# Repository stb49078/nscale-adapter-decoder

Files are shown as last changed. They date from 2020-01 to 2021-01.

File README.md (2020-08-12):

# Lokdecoder - Adapter Platinen und DIY Decoder - Spur N

Hier finden sich div. Adapterplatinen und vollständige DIY Lokdecoder auf Basis des (vermutlich eingestellten)
Projekts [Aegaeon](https://github.com/Railstars/Aegaeon) von [Railstars](http://railstars.com/).

Wie dieses Projekt auch, stehen die hier veröffentlichten Designs damit automatisch unter GPLv3.

Die Dekoder wurden leicht angeändert, und verwenden den Motortreiber
[BD623xx](http://rohmfs.rohm.com/en/products/databook/datasheet/ic/motor/dc/bd623x-e.pdf).

## Arnold

**1020/E94**

[NEM-651 Adapter](./loc-decoder/Arnold/1020/NEM-651_Adapter)
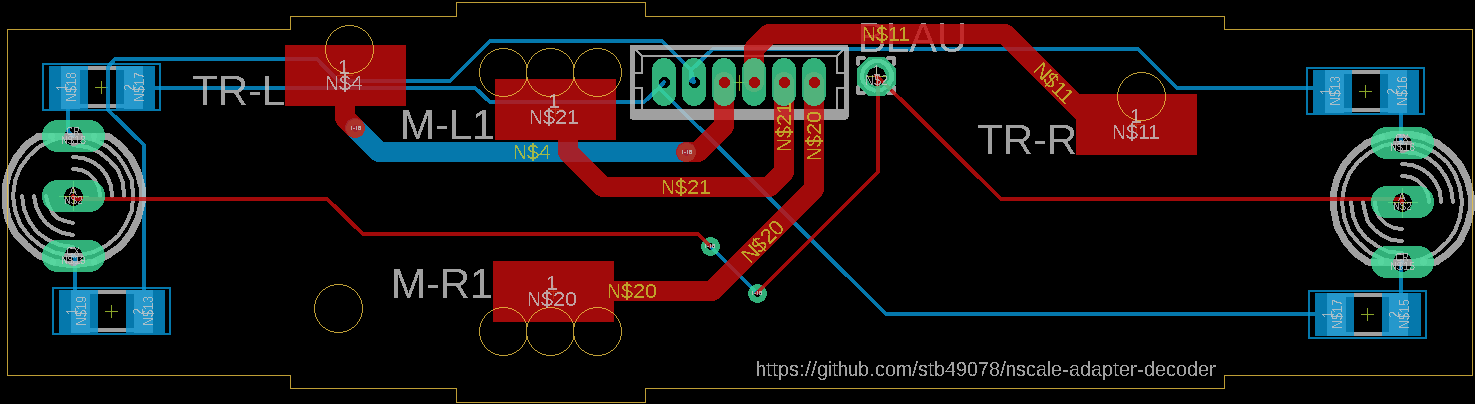
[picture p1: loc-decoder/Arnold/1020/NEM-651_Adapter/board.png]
Board


## Roco

**1044 alt, z.B. 23242**

[NEM-651 Adapter](./loc-decoder/Roco/1044/NEM-651_Adapter)
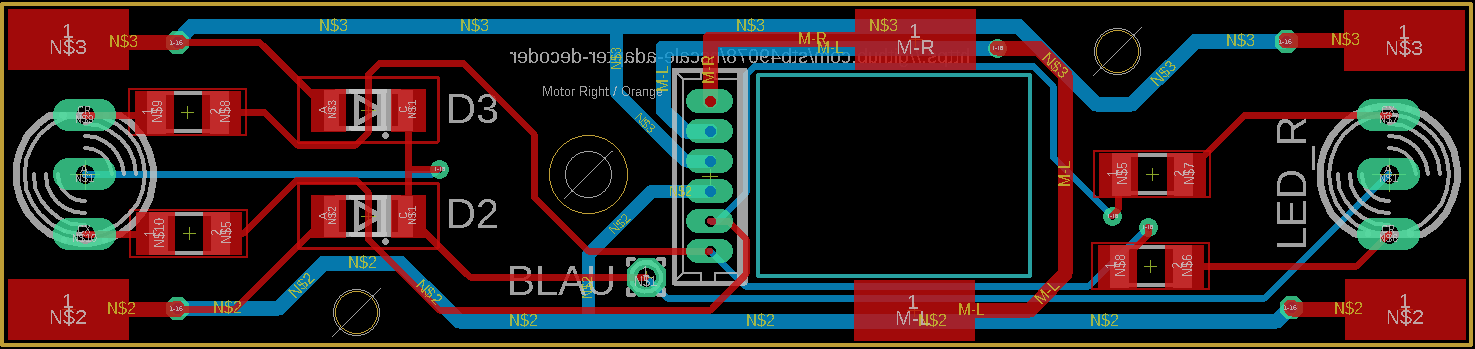
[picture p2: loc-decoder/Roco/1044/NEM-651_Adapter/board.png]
Board


[Aegaeon Decoder mit BD62xx und Railcom](./loc-decoder/Roco/1044/Decoder-BD62xx-Railcom)
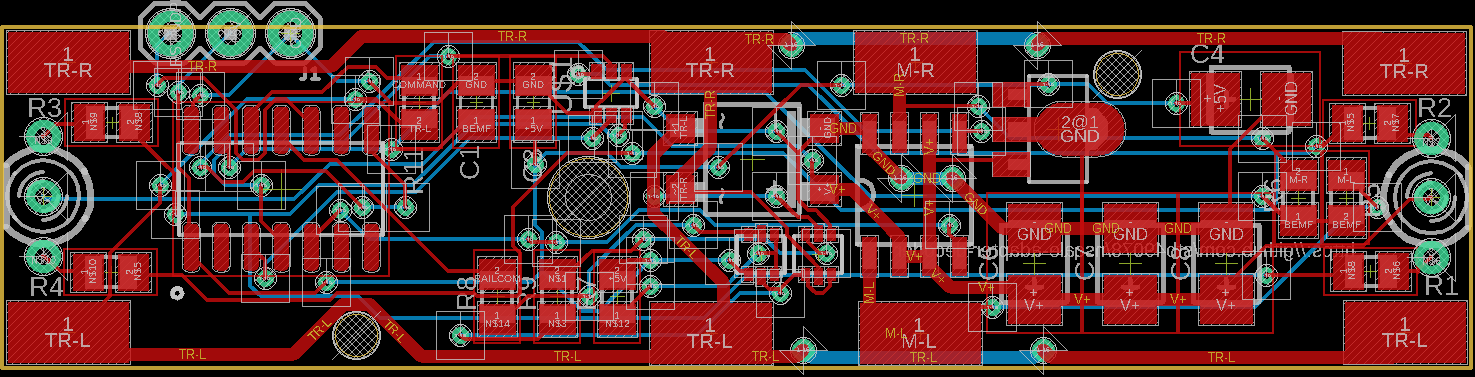
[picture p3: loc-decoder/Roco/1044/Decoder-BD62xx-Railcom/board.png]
Board


**BR215, z.B. 2150B**

[NEM-651 Adapter](./loc-decoder/Roco/BR215/NEM-651_Adapter)
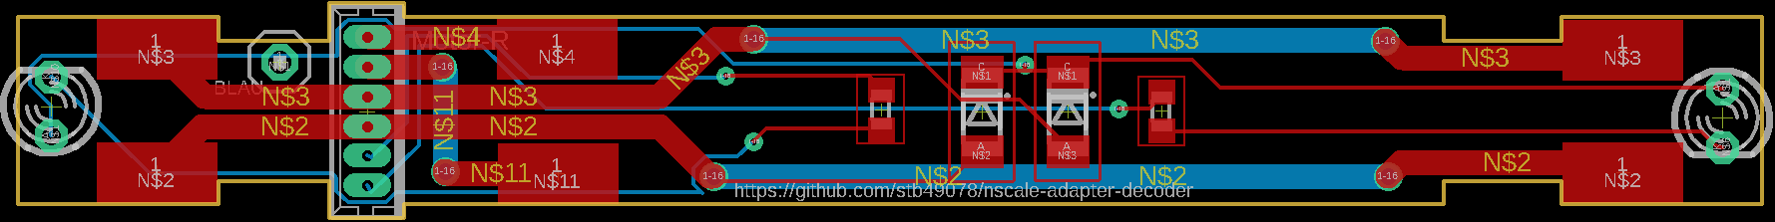
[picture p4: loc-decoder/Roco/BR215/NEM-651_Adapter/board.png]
Board


**BR 44, z.B. 2106B**

[NEM-651 Adapter](./loc-decoder/Roco/BR44/NEM-651_Adapter)
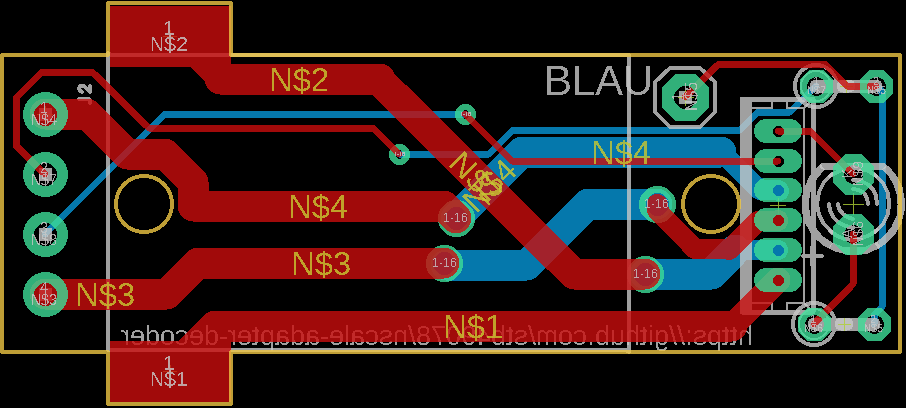
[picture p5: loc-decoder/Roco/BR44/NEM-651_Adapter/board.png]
Board


## Minitrix

**E44**

[NEM-651 Adapter](./loc-decoder/Minitrix/E44/NEM-651_Adapter)
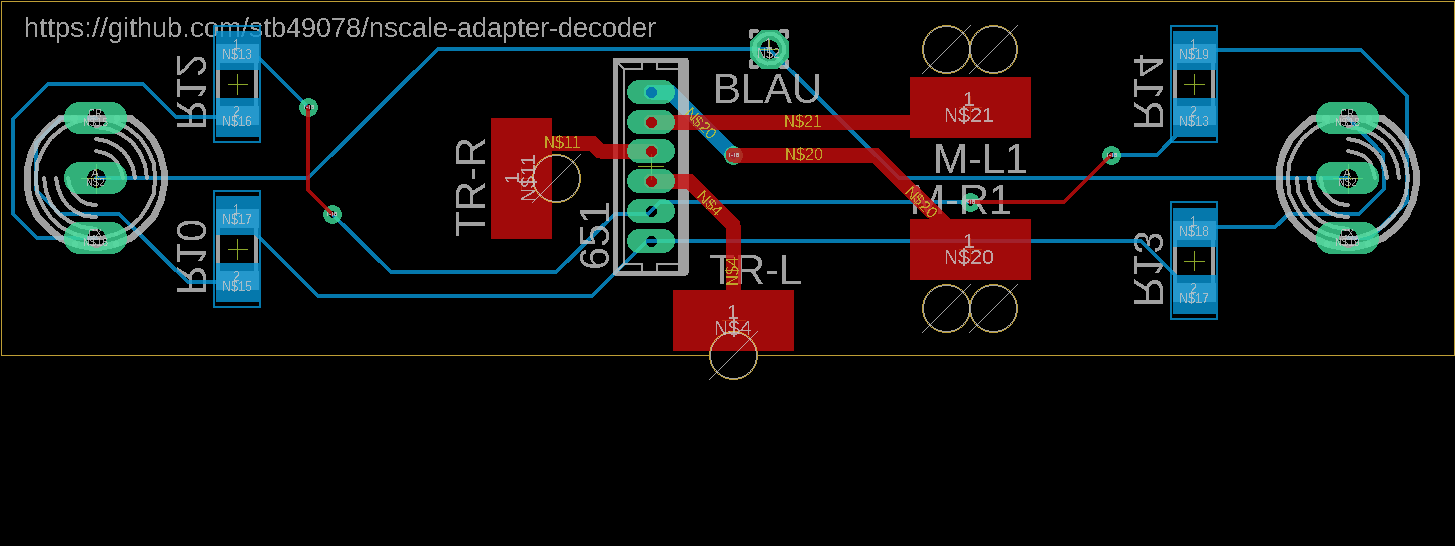
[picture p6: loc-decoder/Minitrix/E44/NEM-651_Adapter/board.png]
Board


## Spectrum

**GE Dash 8-40CW**

[Aegaeon Decoder mit BD62xx und Railcom](./loc-decoder/Spectrum/GE_Dash_8-40CW/Decoder-BD62xx-Railcom)
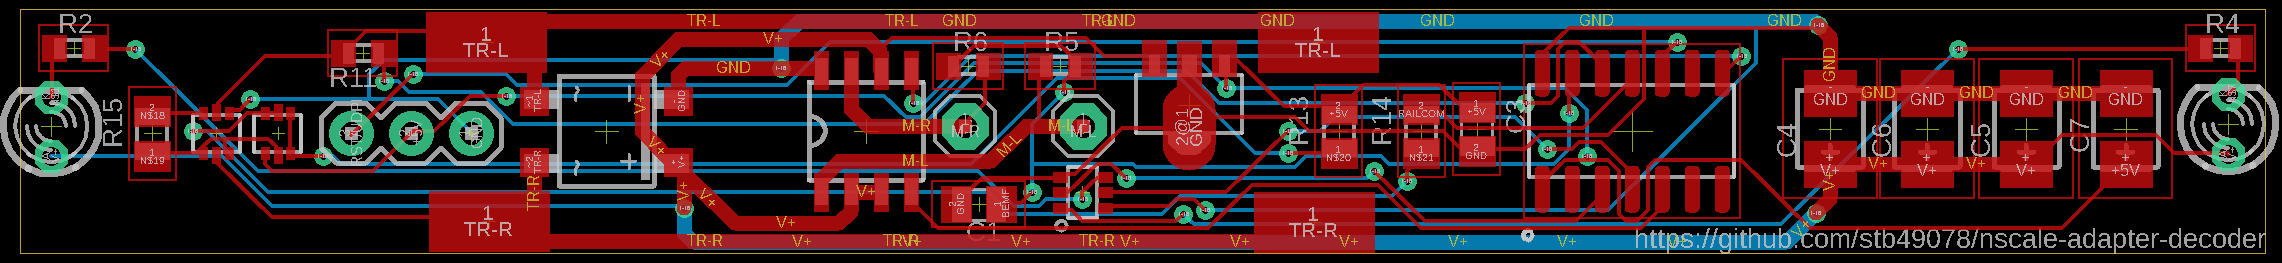
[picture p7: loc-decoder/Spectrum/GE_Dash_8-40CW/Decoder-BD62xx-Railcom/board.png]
Board


# Wagonbeleuchtung mit integriertem Decoder- Spur N

Mit freundlicher Erlaubnis von Hr. Brandt, verwende ich als Basis
für die Wagonbeleuchtung, seinen unter https://www.digital-bahn.de/bau_wald/wald_2v1.htm
veröffentlicheten Spur H0 - Waggon-Licht Dekoder (WaLD) V2.1
Sämtliche Lizenzen für diese Platinen und der darauf verwendeten Software liegen bei digital-bahn.

Diese Platinen werden von meiner Seite nicht zum Verkauf angeboten.
Der Verkauf und/oder Vertrieb eines hier veröffentlichten Designs darf nur unter
Rücksprache mit digital-bahn erfolgen. Copyleft.

Die Anleitung zur Installation der Software und die Schaltungsbeschreibung sind
in der oben genannten Seite zu finden.

Die originale H0-Platine und vorprogrammierte PIC-Controller können im Shop von
digital-bahn unter https://digital-bahn.de/shopping/Waggon-Beleuchtung bezogen werden.  

Folgende Modelle werden aktuell unterstützt:

[Roco - Eurofima z.B. 24270, 24285, uvm.](./wagon-light/Roco/Eurofima)
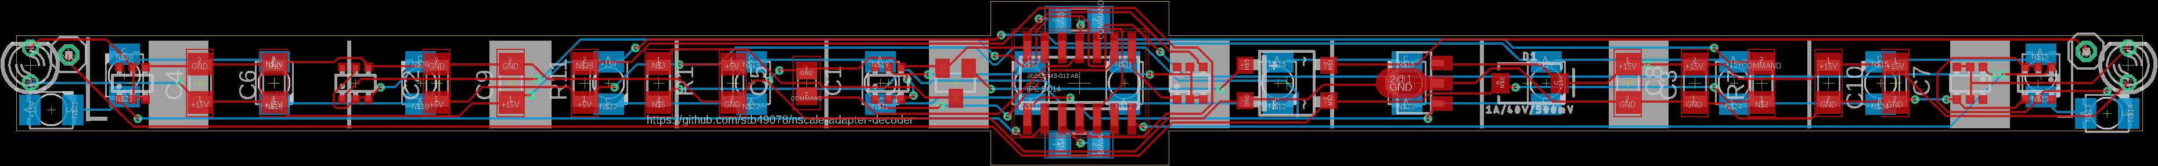
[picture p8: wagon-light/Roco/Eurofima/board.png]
Board


[Roco - Eilzugwagen / Schlierenwagen z.B. 24280-24281 ](./wagon-light/Roco/Eilzugwagen)
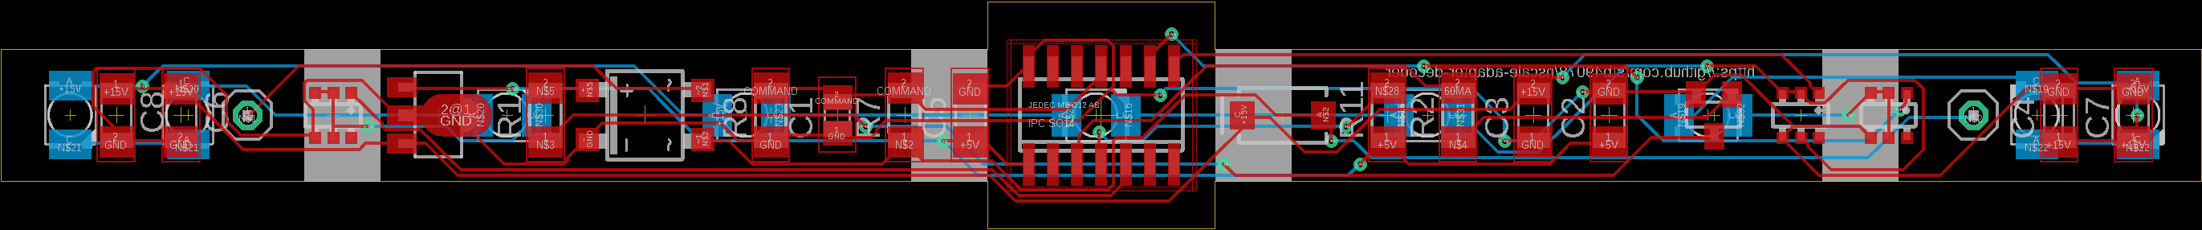
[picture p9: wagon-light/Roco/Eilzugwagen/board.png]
Board


[Minitrix - Eurofima z.B. 3095, 3106, uvm.](./wagon-light/Minitrix/Eurofima)
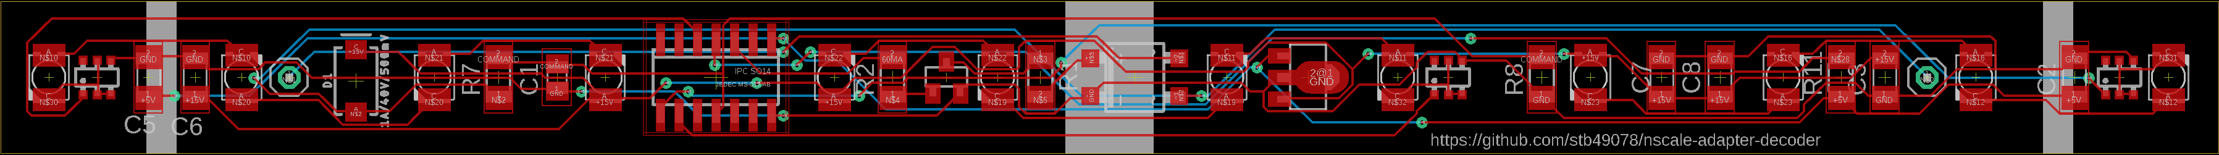
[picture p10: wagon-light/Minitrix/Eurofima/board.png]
Board


Für kleinere Wägen gibt es allgemeine Platinen

[Einseite Montage - 50mm * 15mm](./wagon-light/common/50x15)
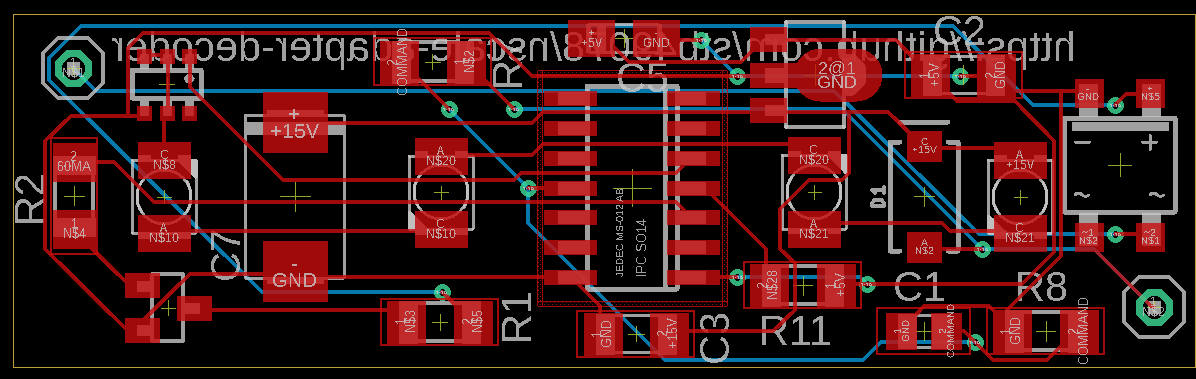
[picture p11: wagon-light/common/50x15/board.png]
Board


## Support und Fragen

Bei Fragen, Anregungen und Beschwerden, bitte einfach unter spur.n@stefanbauer.at melden.

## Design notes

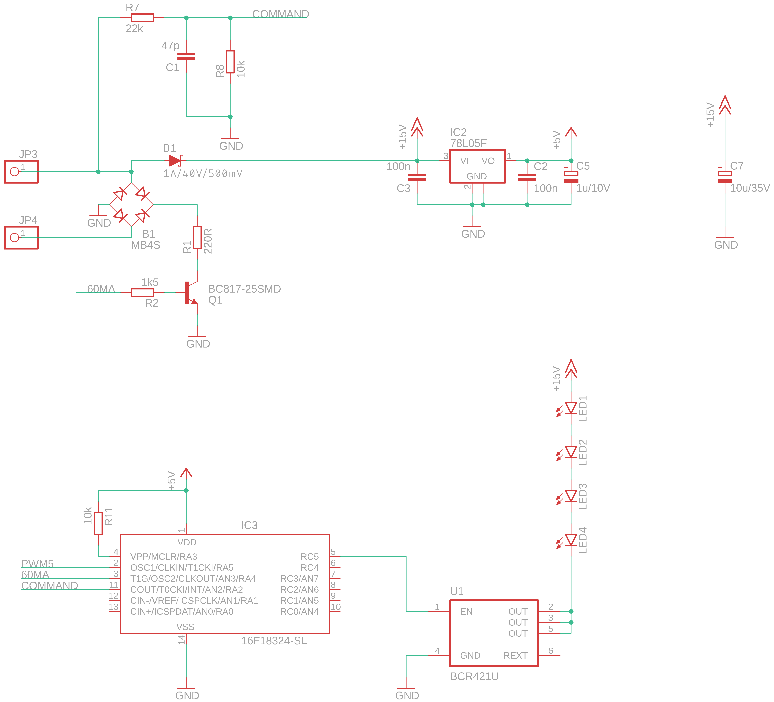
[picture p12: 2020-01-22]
wagon-light/common/50x15/schematic.png

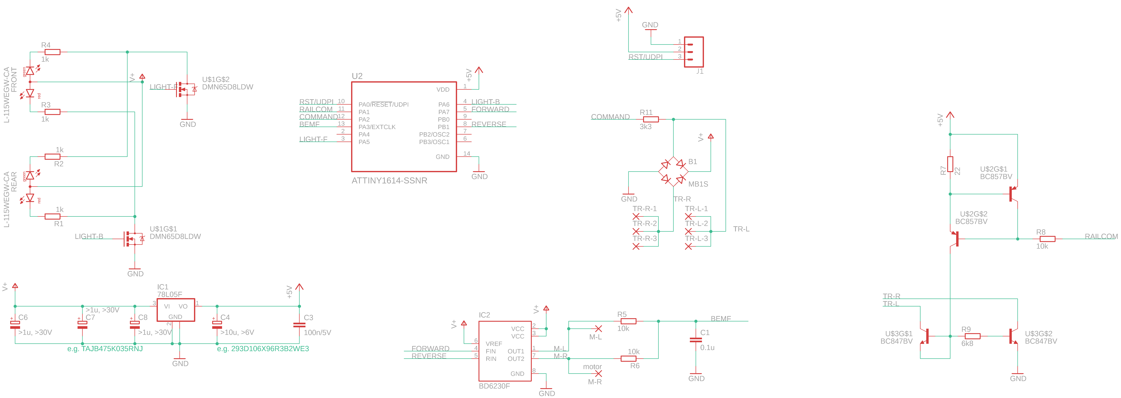
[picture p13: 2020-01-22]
loc-decoder/Roco/1044/Decoder-BD62xx-Railcom/schematic.png

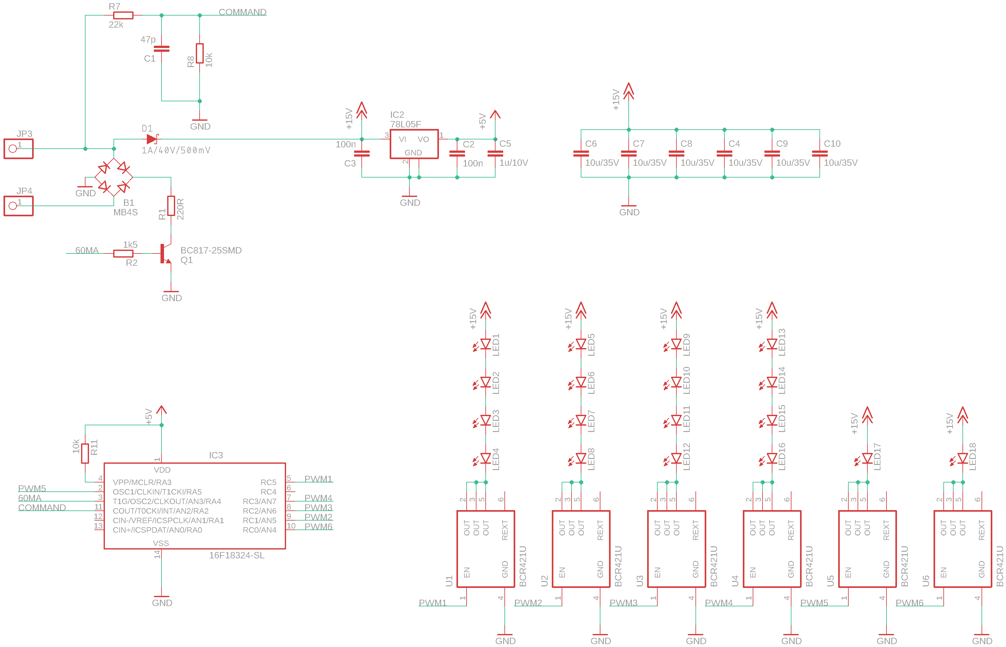
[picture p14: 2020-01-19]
wagon-light/Roco/Eurofima/schematic.png

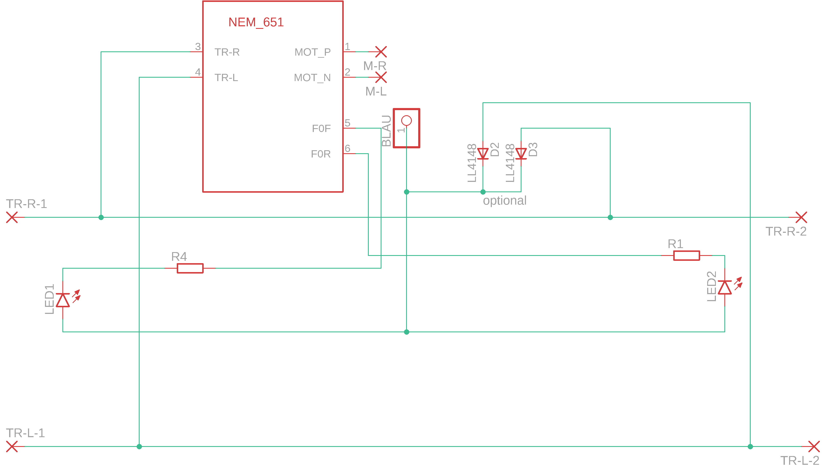
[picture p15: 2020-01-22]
loc-decoder/Roco/BR215/NEM-651_Adapter/schematic.png

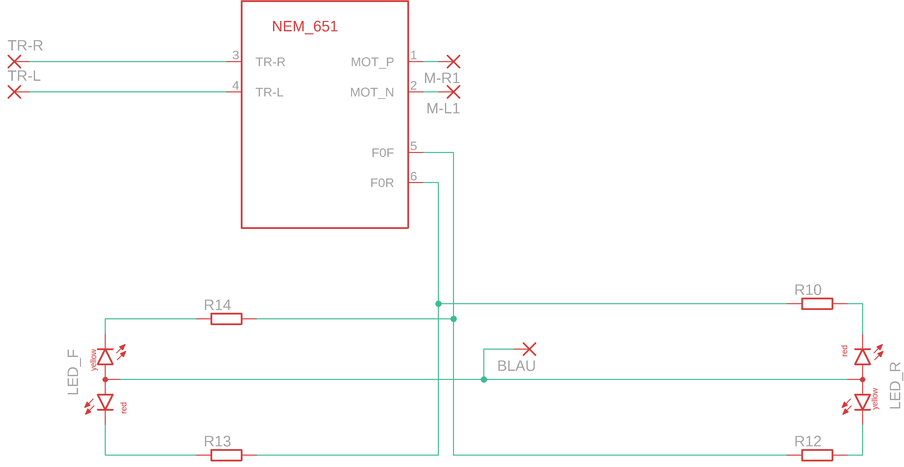
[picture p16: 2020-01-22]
loc-decoder/Minitrix/E44/NEM-651_Adapter/schematic.png

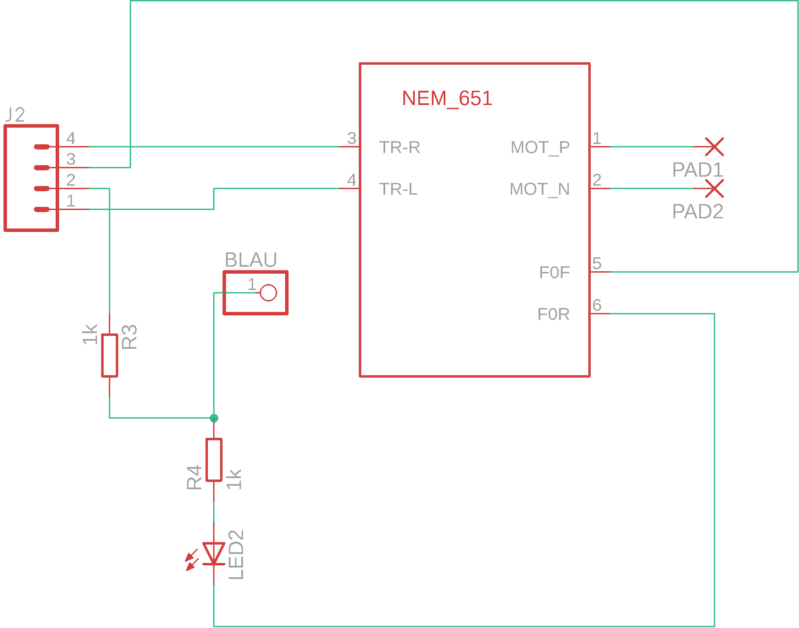
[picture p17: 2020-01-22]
loc-decoder/Roco/BR44/NEM-651_Adapter/schematic.png

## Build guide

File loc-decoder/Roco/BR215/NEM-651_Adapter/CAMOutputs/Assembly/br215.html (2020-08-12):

Stückliste exportiert aus D:/nscale-adapter-decoder/loc-decoder/Roco/BR215/br215.sch am 22.01.2020 22:11

Qty | Value | Device | Package | Parts | Description | POPULARITY | SPICEPREFIX
2 | | LED3MM | LED3MM | LED1, LED2 | LED
1 | | PINHD-1X1 | 1X01 | BLAU | PIN HEADER | 64
2 | | R-EU_R0603 | R0603 | R1, R4 | RESISTOR, European symbol | | R
6 | | SMD5 | SMD2,54-5,08 | M-L, M-R, TR-L-1, TR-L-2, TR-R-1, TR-R-2 | SMD PAD
2 | LL4148 | LL4148 | SOD80_DO213AA_MINIMELF | D2, D3 | 1N4148 General Purpose Rectifie
1 | NEM_651-TS | NEM_651-TS | 53047-06 | 651 | NEM651

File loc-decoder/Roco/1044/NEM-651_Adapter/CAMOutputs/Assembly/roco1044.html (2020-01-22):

Stückliste exportiert aus D:/nscale-adapter-decoder/loc-decoder/Roco/1044/NEM-651 Adapter/roco1044.sch am 22.01.2020 21:57

Qty | Value | Device | Package | Parts | Description | SPICEPREFIX
1 | | 1,6/0,8 | 1,6/0,8 | BLAU | THROUGH-HOLE PAD
2 | | DUOLED-RY-A | DUOLED-A-5MM | LED_F, LED_R | DUO LED
4 | | R-EU_R1206 | R1206 | R1, R2, R3, R4 | RESISTOR, European symbol | R
6 | | SMD5 | SMD2,54-5,08 | M-L, M-R, TR-L-1, TR-L-2, TR-R-1, TR-R-2 | SMD PAD
2 | LL4148 | LL4148 | SOD80_DO213AA_MINIMELF | D2, D3 | 1N4148 General Purpose Rectifie
1 | NEM_651-TS | NEM_651-TS | 53047-06 | 651 | NEM651

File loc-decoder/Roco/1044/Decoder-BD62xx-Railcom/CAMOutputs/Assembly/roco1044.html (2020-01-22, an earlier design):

Stückliste exportiert aus D:/nscale-adapter-decoder/loc-decoder/Roco/1044/Decoder-BD62xx-Railcom/roco1044.sch am 22.01.2020 22:04

Qty | Value | Device | Package | Parts | Description | AVAILABILITY | DESCRIPTION | MF | MP | MPN | OC_FARNELL | OC_NEWARK | PACKAGE | POPULARITY | PRICE | PROD_ID | SPICEPREFIX | VALUE
7 | | SMD5 | SMD2,54-5,08 | M-L, TR-L-1, TR-L-2, TR-L-3, TR-R-1, TR-R-2, TR-R-3 | SMD PAD
1 | 0.1u | C-EUC0805 | C0805 | C1 | CAPACITOR, European symbol
1 | 100n/5V | C-EUC0805 | C0805 | C3 | CAPACITOR, European symbol | | | | | | | | | | | | C
3 | 10k | R-EU_R0805 | R0805 | R5, R6, R8 | RESISTOR, European symbol | | | | | | | | | 86 | | | R
4 | 1k | R-EU_R0805 | R0805 | R1, R2, R3, R4 | RESISTOR, European symbol | | | | | | | | | 86 | | | R
1 | 22 | R-EU_R0805 | R0805 | R7 | RESISTOR, European symbol | | | | | | | | | 86 | | | R
1 | 3k3 | R-EU_R0805 | R0805 | R11 | RESISTOR, European symbol | | | | | | | | | 86 | | | R
1 | 455-1750-1-ND | CONN_03 | 1X03 | J1 | Multi connection point. Often used as Generic Header-pin footprint for 0.1 inch spaced/style header connections | | | | | | | | | | | XXX-00000 | | 455-1750-1-ND
1 | 6k8 | R-EU_R0805 | R0805 | R9 | RESISTOR, European symbol | | | | | | | | | 86 | | | R
1 | 78L05F | 78L05F | SOT89 | IC1 | POSITOIV-VOLTAGE REGULATORS
1 | >10u, >6V | CPOL-EUCT3528 | CT3528 | C4 | POLARIZED CAPACITOR, European symbol | | | | | | | | | 1 | | | C
3 | >1u, >30V | CPOL-EUCT3528 | CT3528 | C6, C7, C8 | POLARIZED CAPACITOR, European symbol | | | | | | | | | 1 | | | C
1 | ATTINY1614-SSNR | ATTINY1614-SSNR | SOIC127P600X175-14N | U2 | 20MHz, SOIC, 85C, Green, 14 SOIC .150in T/R | Unavailable | AVR tinyAVR™ 1 Microcontroller IC 8-Bit 20MHz 16KB _16K x 8_ FLASH 14-SOIC | Microchip | ATTINY1614-SSNR | | | | SO-14 Microchip | | None
1 | BC847BV | BC847BV | SOT-666 | U$3
1 | BC857BV | BC857BV | SOT-666 | U$2
1 | BD6230F | BD6230F | SOP8 | IC2 | H-bridge driver for brush motors | | | | | BD6230F-E2 | 1716264 | 15R0529
1 | DMN65D8LDW | DMN65D8LDW | SOT363 | U$1
2 | L-115WEGW-CA | L-115WEGW-CA | DUOLED-A-3MM | FRONT, REAR | T-1(3mm) BI-COLOR INDICATOR LAMP
1 | MB1S | MB1S | SOIC-4 | B1 | Bridge Rectifier
1 | motor | SMD5 | SMD2,54-5,08 | M-R | SMD PAD

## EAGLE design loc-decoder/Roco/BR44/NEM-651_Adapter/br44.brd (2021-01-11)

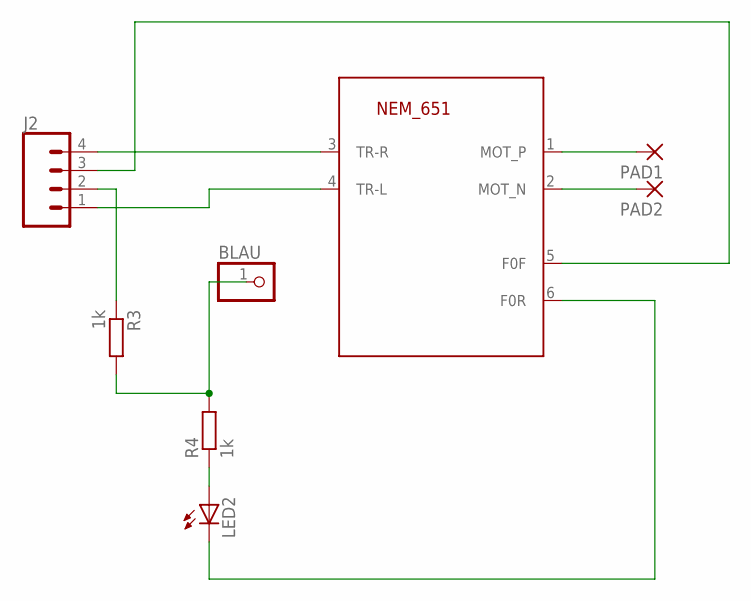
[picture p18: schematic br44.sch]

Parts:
BLAU: PINHD-1X1; 1X01
J2: CONN_041X04_NO_SILK; 1X04_NO_SILK
LED2: LED3MM
PAD1, PAD2: SMD5; SMD2,54-5,08
R3, R4: 1k; 0204V
U$1: NEM_651-TS; 53047-06

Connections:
unnamed: PAD1.1, U$1.1 (MOT_P)
unnamed: PAD2.1, U$1.2 (MOT_N)
unnamed: J2.4, U$1.3 (TR-R)
unnamed: J2.1, U$1.4 (TR-L)
unnamed: BLAU.1, R3.2, R4.2
unnamed: LED2.A, R4.1
unnamed: J2.2, R3.1
unnamed: J2.3, U$1.5 (F0F)
unnamed: LED2.K (C), U$1.6 (F0R)

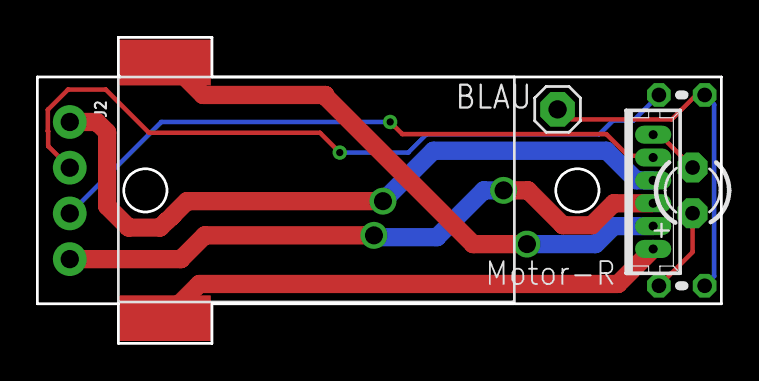
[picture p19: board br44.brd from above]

Board: 2 copper layers, 38.0 x 17.0 mm, 8 parts (0 on the bottom side), 9 nets.

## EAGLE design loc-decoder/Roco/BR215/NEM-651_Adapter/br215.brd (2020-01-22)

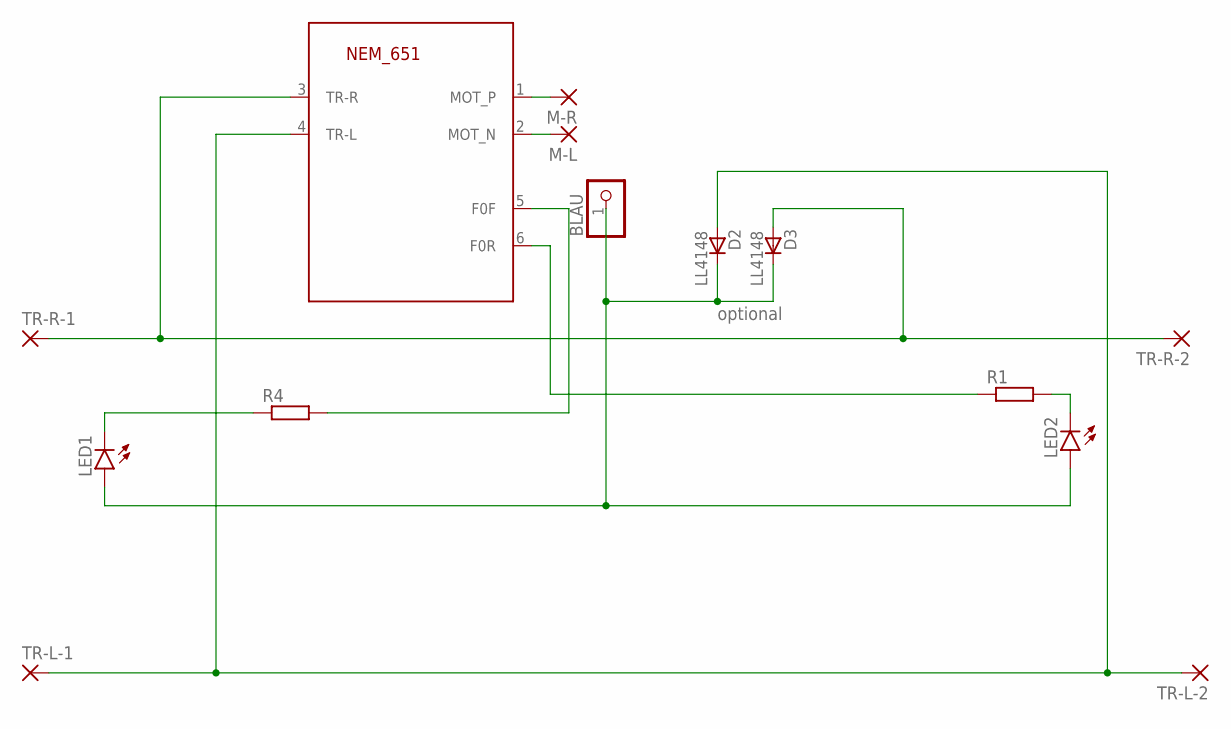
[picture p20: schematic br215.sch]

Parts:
651: NEM_651-TS; 53047-06
BLAU: PINHD-1X1; 1X01
D2, D3: LL4148; SOD80_DO213AA_MINIMELF
LED1, LED2: LED3MM
M-L: SMD5; SMD2,54-5,08
M-R: SMD5; SMD2,54-5,08
R1, R4: R-EU_R0603; R0603
TR-L-1, TR-L-2: SMD5; SMD2,54-5,08
TR-R-1, TR-R-2: SMD5; SMD2,54-5,08

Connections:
unnamed: BLAU.1, D2.C, D3.C, LED1.A, LED2.A
unnamed: 651.4 (TR-L), D2.A, TR-L-1.1, TR-L-2.1
unnamed: 651.3 (TR-R), D3.A, TR-R-1.1, TR-R-2.1
unnamed: 651.1 (MOT_P), M-R.1
unnamed: 651.5 (F0F), R4.2
unnamed: LED2.K (C), R1.2
unnamed: 651.6 (F0R), R1.1
unnamed: LED1.K (C), R4.1
unnamed: 651.2 (MOT_N), M-L.1

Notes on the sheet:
optional

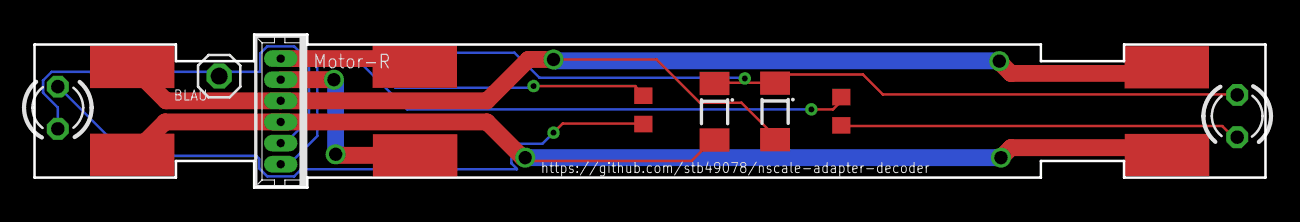
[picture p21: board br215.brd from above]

Board: 2 copper layers, 74.0 x 9.2 mm, 14 parts (0 on the bottom side), 9 nets.

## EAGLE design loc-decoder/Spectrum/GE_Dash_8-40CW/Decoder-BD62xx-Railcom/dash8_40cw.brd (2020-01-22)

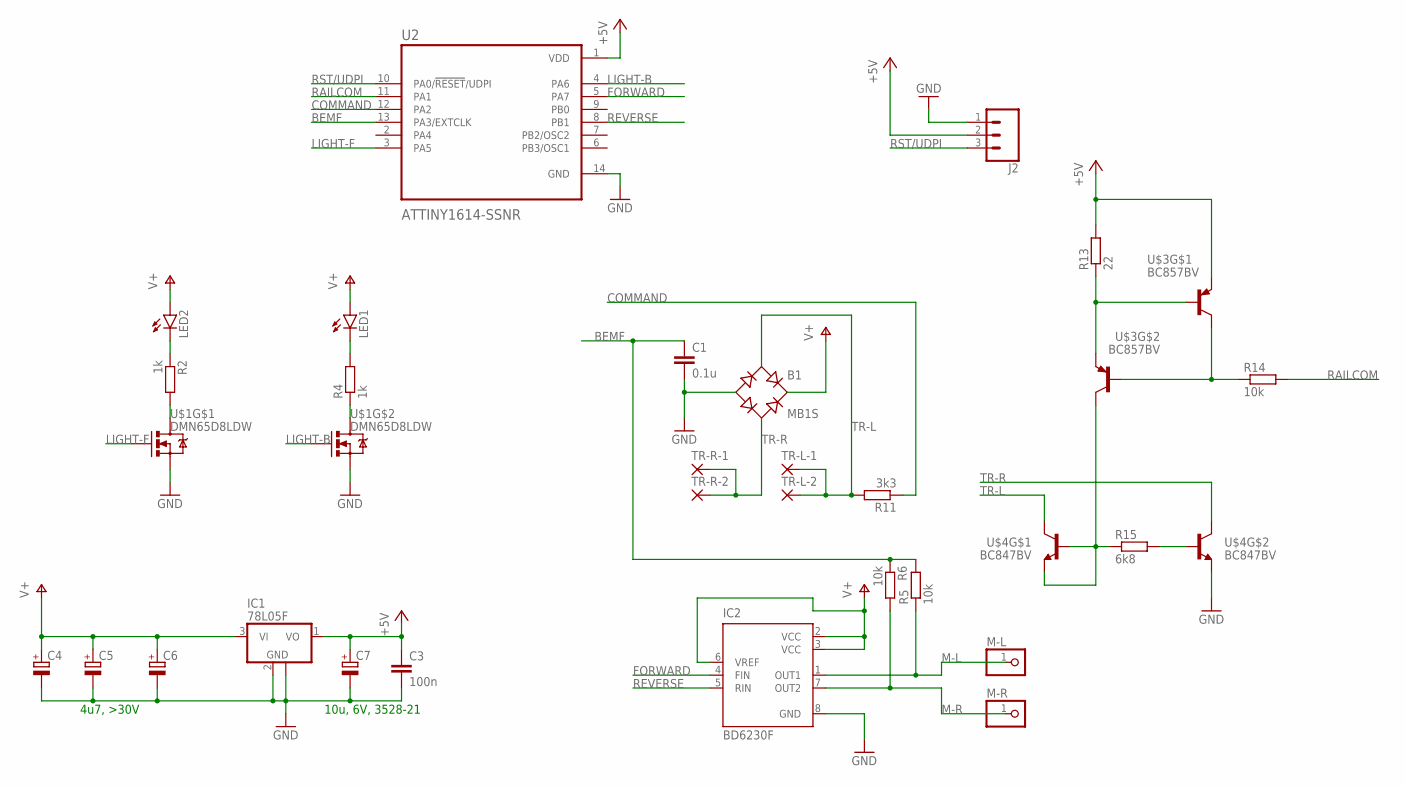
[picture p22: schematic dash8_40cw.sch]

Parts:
B1: MB1S; SOIC-4
C1: 0.1u; C0805
C3: 100n; C0805
C4, C5, C6, C7: CPOL-EUCT3528; CT3528
IC1: 78L05F; SOT89
IC2: BD6230F; SOP8
J2: 455-1750-1-ND; 1X03
LED1, LED2: LED3MM
M-L: PINHD-1X1; 1X01
M-R: PINHD-1X1; 1X01
R2, R4: 1k; R0603
R5, R6: 10k; R0603
R11: 3k3; R0603
R13: 22; R0805
R14: 10k; R0805
R15: 6k8; R0805
TR-L-1, TR-L-2: SMD5; SMD2,54-5,08
TR-R-1, TR-R-2: SMD5; SMD2,54-5,08
U2: ATTINY1614-SSNR; SOIC127P600X175-14N
U$1: DMN65D8LDW; SOT363
U$3: BC857BV; SOT-666
U$4: BC847BV; SOT-666

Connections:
+5V: C3.1, C7.+, IC1.1 (VO), J2.2, R13.2, U2.1 (VDD), U$3.P$1 (E)
BEMF: C1.1, R5.2, R6.1, U2.13 (PA3/EXTCLK)
COMMAND: R11.1, U2.12 (PA2)
FORWARD: IC2.4 (FIN), U2.5 (PA7)
GND: B1.-, C1.2, C3.2, C4.-, C5.-, C6.-, C7.-, IC1.2 (GND), IC1.2@1 (GND), IC2.8 (GND), J2.1, U2.14 (GND), U$1.P$3 (S), U$1.P$6 (S), U$4.P$4 (E)
LIGHT-B: U2.4 (PA6), U$1.P$5 (G)
LIGHT-F: U2.3 (PA5), U$1.P$2 (G)
M-L: IC2.1 (OUT1), M-L.1, R5.1
M-R: IC2.7 (OUT2), M-R.1, R6.2
unnamed: LED2.K (C), R2.1
unnamed: R4.1, U$1.P$1 (D)
unnamed: R2.2, U$1.P$4 (D)
unnamed: LED1.K (C), R4.2
unnamed: R15.2, U$4.P$5 (B)
unnamed: R15.1, U$3.P$3 (C), U$4.P$1 (E), U$4.P$2 (B)
unnamed: R13.1, U$3.P$2 (B), U$3.P$4 (E)
unnamed: R14.1, U$3.P$5 (B), U$3.P$6 (C)
RAILCOM: R14.2, U2.11 (PA1)
REVERSE: IC2.5 (RIN), U2.8 (PB1)
RST/UDPI: J2.3, U2.10 (PA0/!RESET!/UDPI)
TR-L: B1.~1 (AC1), R11.2, TR-L-1.1, TR-L-2.1, U$4.P$6 (C)
TR-R: B1.~2 (AC2), TR-R-1.1, TR-R-2.1, U$4.P$3 (C)
V+: B1.+, C4.+, C5.+, C6.+, IC1.3 (VI), IC2.2 (VCC), IC2.3 (VCC), IC2.6 (VREF), LED1.A, LED2.A

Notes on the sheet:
4u7, >30V
10u, 6V, 3528-21

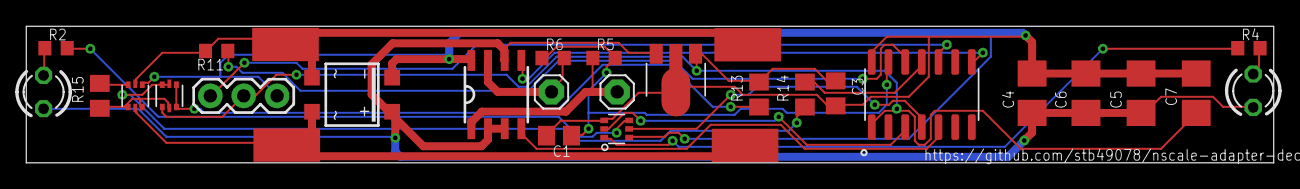
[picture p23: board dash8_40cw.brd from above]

Board: 2 copper layers, 95.0 x 10.4 mm, 30 parts (0 on the bottom side), 23 nets.

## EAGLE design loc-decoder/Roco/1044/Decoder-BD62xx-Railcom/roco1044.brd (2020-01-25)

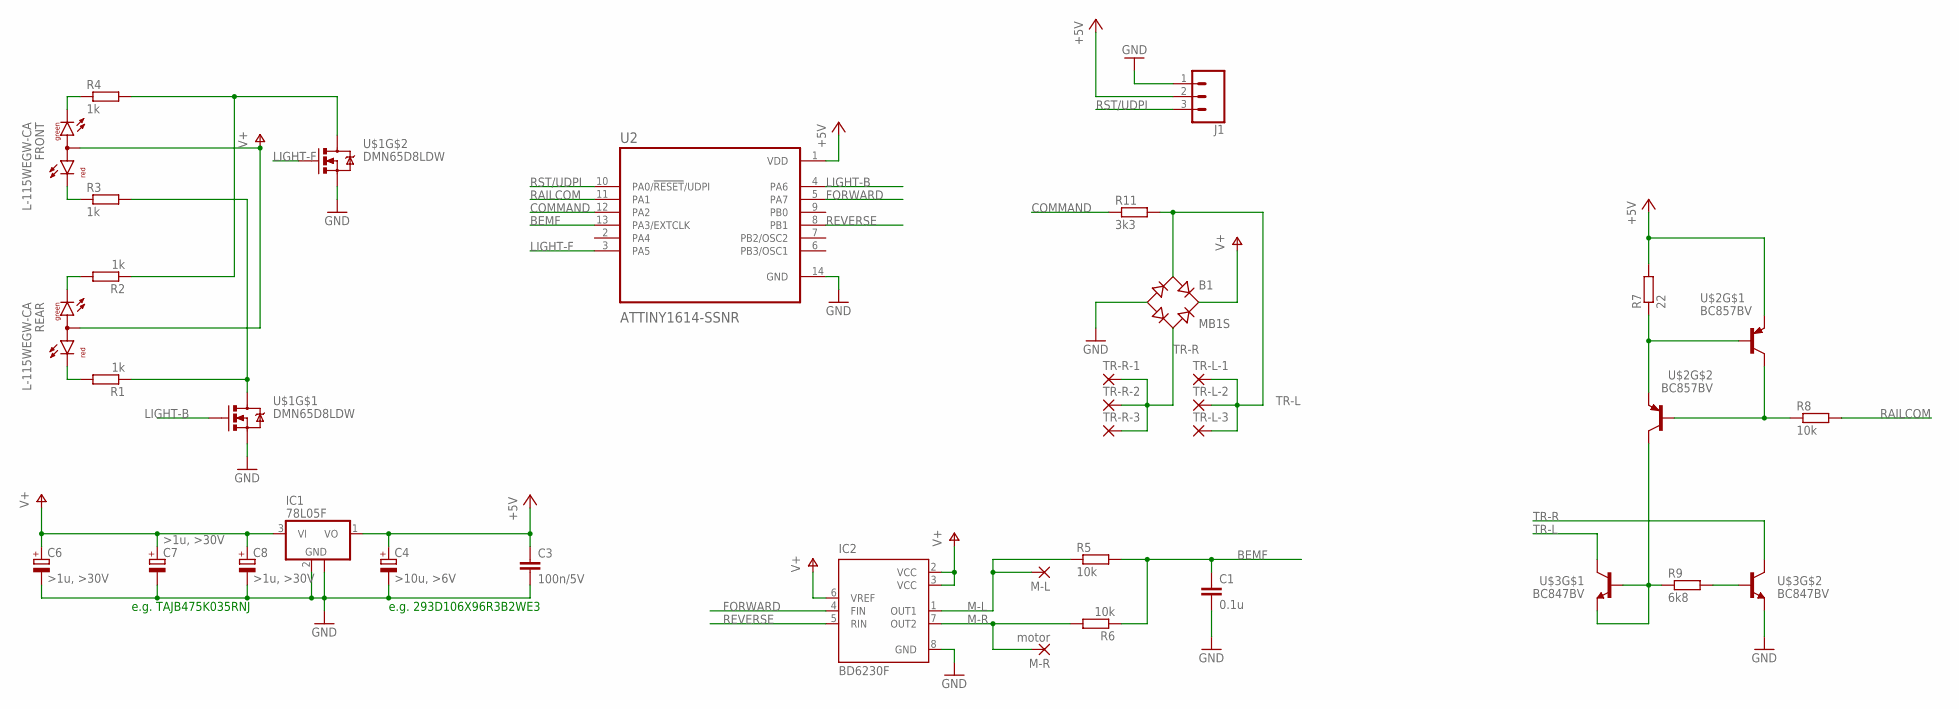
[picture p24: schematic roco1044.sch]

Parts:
B1: MB1S; SOIC-4
C1: 0.1u; C0805
C3: 100n/5V; C0805
C4: >10u, >6V; CT3528
C6, C7, C8: >1u, >30V; CT3528
FRONT: L-115WEGW-CA; DUOLED-A-3MM
IC1: 78L05F; SOT89
IC2: BD6230F; SOP8
J1: 455-1750-1-ND; 1X03
M-L: SMD5; SMD2,54-5,08
M-R: motor; SMD2,54-5,08
R1, R2, R3, R4: 1k; R0805
R5, R6, R8: 10k; R0805
R7: 22; R0805
R9: 6k8; R0805
R11: 3k3; R0805
REAR: L-115WEGW-CA; DUOLED-A-3MM
TR-L-1, TR-L-2, TR-L-3: SMD5; SMD2,54-5,08
TR-R-1, TR-R-2, TR-R-3: SMD5; SMD2,54-5,08
U2: ATTINY1614-SSNR; SOIC127P600X175-14N
U$1: DMN65D8LDW; SOT363
U$2: BC857BV; SOT-666
U$3: BC847BV; SOT-666

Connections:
+5V: C3.1, C4.+, IC1.1 (VO), J1.2, R7.2, U2.1 (VDD), U$2.P$1 (E)
BEMF: C1.1, R5.2, R6.1, U2.13 (PA3/EXTCLK)
COMMAND: R11.1, U2.12 (PA2)
FORWARD: IC2.4 (FIN), U2.5 (PA7)
GND: B1.-, C1.2, C3.2, C4.-, C6.-, C7.-, C8.-, IC1.2 (GND), IC1.2@1 (GND), IC2.8 (GND), J1.1, U2.14 (GND), U$1.P$3 (S), U$1.P$6 (S), U$3.P$4 (E)
LIGHT-B: U2.4 (PA6), U$1.P$2 (G)
LIGHT-F: U2.3 (PA5), U$1.P$5 (G)
M-L: IC2.1 (OUT1), M-L.1, R5.1
M-R: IC2.7 (OUT2), M-R.1, R6.2
unnamed: R9.2, U$3.P$5 (B)
unnamed: R9.1, U$2.P$3 (C), U$3.P$1 (E), U$3.P$2 (B)
unnamed: R2.1, R4.2, U$1.P$1 (D)
unnamed: R1.2, REAR.3 (CR)
unnamed: R2.2, REAR.1 (CG)
unnamed: R1.1, R3.2, U$1.P$4 (D)
unnamed: FRONT.3 (CR), R3.1
unnamed: FRONT.1 (CG), R4.1
unnamed: R7.1, U$2.P$2 (B), U$2.P$4 (E)
unnamed: R8.1, U$2.P$5 (B), U$2.P$6 (C)
RAILCOM: R8.2, U2.11 (PA1)
REVERSE: IC2.5 (RIN), U2.8 (PB1)
RST/UDPI: J1.3, U2.10 (PA0/!RESET!/UDPI)
TR-L: B1.~1 (AC1), R11.2, TR-L-1.1, TR-L-2.1, TR-L-3.1, U$3.P$6 (C)
TR-R: B1.~2 (AC2), TR-R-1.1, TR-R-2.1, TR-R-3.1, U$3.P$3 (C)
V+: B1.+, C6.+, C7.+, C8.+, FRONT.2 (A), IC1.3 (VI), IC2.2 (VCC), IC2.3 (VCC), IC2.6 (VREF), REAR.2 (A)

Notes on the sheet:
e.g. TAJB475K035RNJ
e.g. 293D106X96R3B2WE3

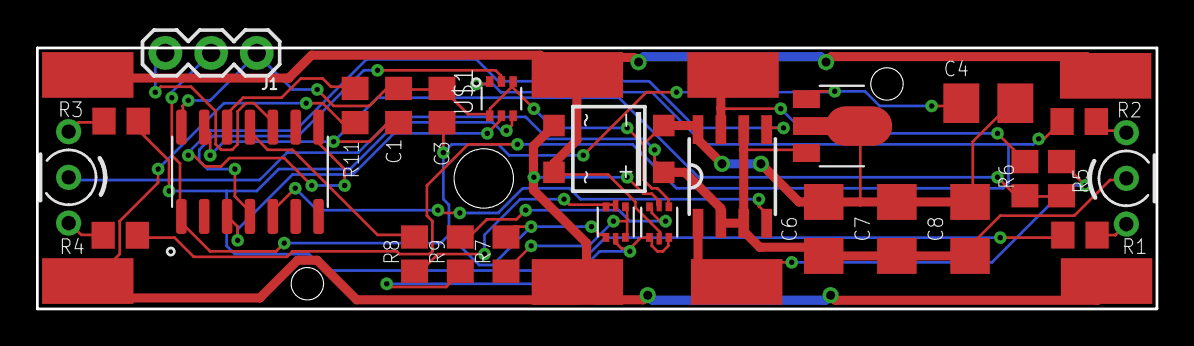
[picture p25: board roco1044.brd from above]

Board: 2 copper layers, 62.2 x 14.5 mm, 34 parts (0 on the bottom side), 25 nets.

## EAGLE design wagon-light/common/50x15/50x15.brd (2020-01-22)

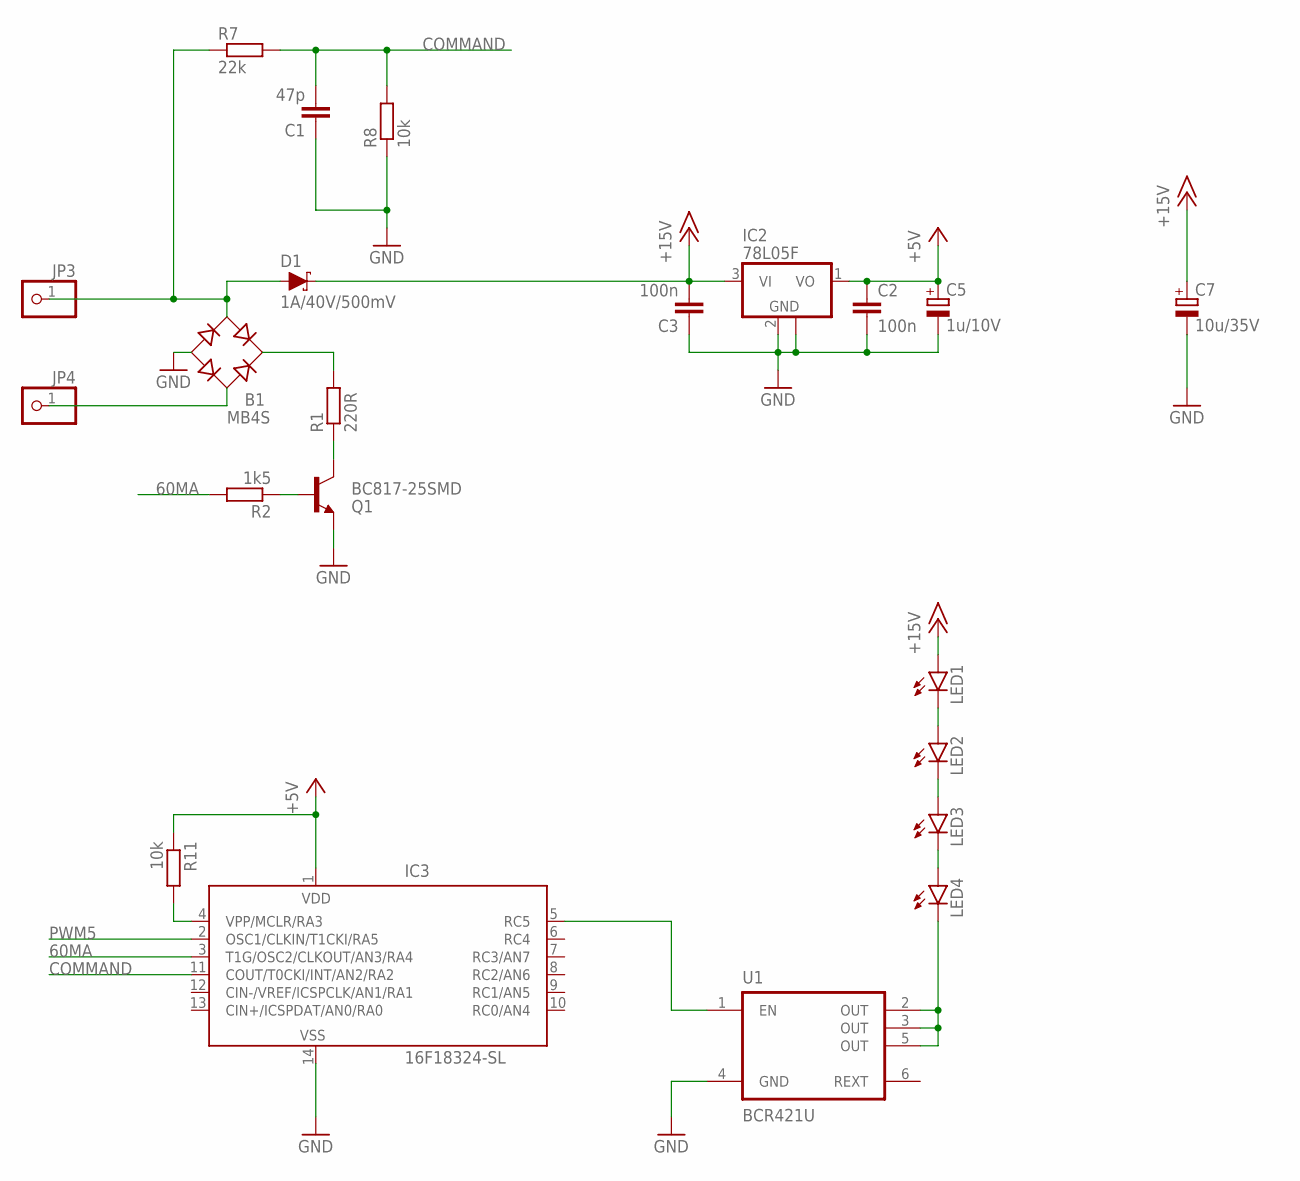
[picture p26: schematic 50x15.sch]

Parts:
B1: MB4S; SOIC-4
C1: 47p; C0805
C2, C3: 100n; C3216
C5: 1u/10V; A/3216-18R
C7: 10u/35V; D/7343-31R
D1: 1A/40V/500mV; SMA-DIODE
IC2: 78L05F; SOT89
IC3: 16F18324-SL; SO-14
JP3, JP4: PINHD-1X1; 1X01
LED1, LED2, LED3, LED4: LEDKA-3528ASYC; KA-3528ASYC
Q1: BC817-25SMD; SOT23-BEC
R1: 220R; R1206
R2: 1k5; R1206
R7: 22k; R1206
R8, R11: 10k; R1206
U1: BCR421U; SC74-6

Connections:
60MA: IC3.3 (T1G/OSC2/CLKOUT/AN3/RA4), R2.2
+5V: C2.1, C5.+, IC2.1 (VO), IC3.1 (VDD), R11.1
+15V: C3.2, C7.+, D1.C, IC2.3 (VI), LED1.A
COMMAND: C1.2, IC3.11 (COUT/T0CKI/INT/AN2/RA2), R7.2, R8.2
GND: B1.-, C1.1, C2.2, C3.1, C5.-, C7.-, IC2.2 (GND), IC2.2@1 (GND), IC3.14 (VSS), Q1.E, R8.1, U1.4 (GND)
unnamed: B1.~2 (AC2), JP4.1
unnamed: B1.~1 (AC1), D1.A, JP3.1, R7.1
unnamed: Q1.C, R1.1
unnamed: Q1.B, R2.1
unnamed: B1.+, R1.2
unnamed: IC3.5 (RC5), U1.1 (EN)
unnamed: LED4.C, U1.2 (OUT), U1.3 (OUT), U1.5 (OUT)
unnamed: LED3.C, LED4.A
unnamed: LED2.C, LED3.A
unnamed: LED1.C, LED2.A
unnamed: IC3.4 (VPP/MCLR/RA3), R11.2
PWM5: IC3.2 (OSC1/CLKIN/T1CKI/RA5)

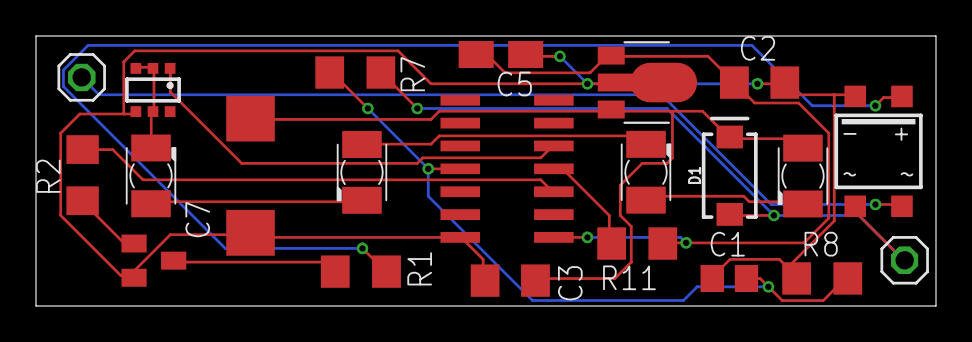
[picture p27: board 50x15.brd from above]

Board: 2 copper layers, 50.0 x 15.0 mm, 22 parts (0 on the bottom side), 16 nets.

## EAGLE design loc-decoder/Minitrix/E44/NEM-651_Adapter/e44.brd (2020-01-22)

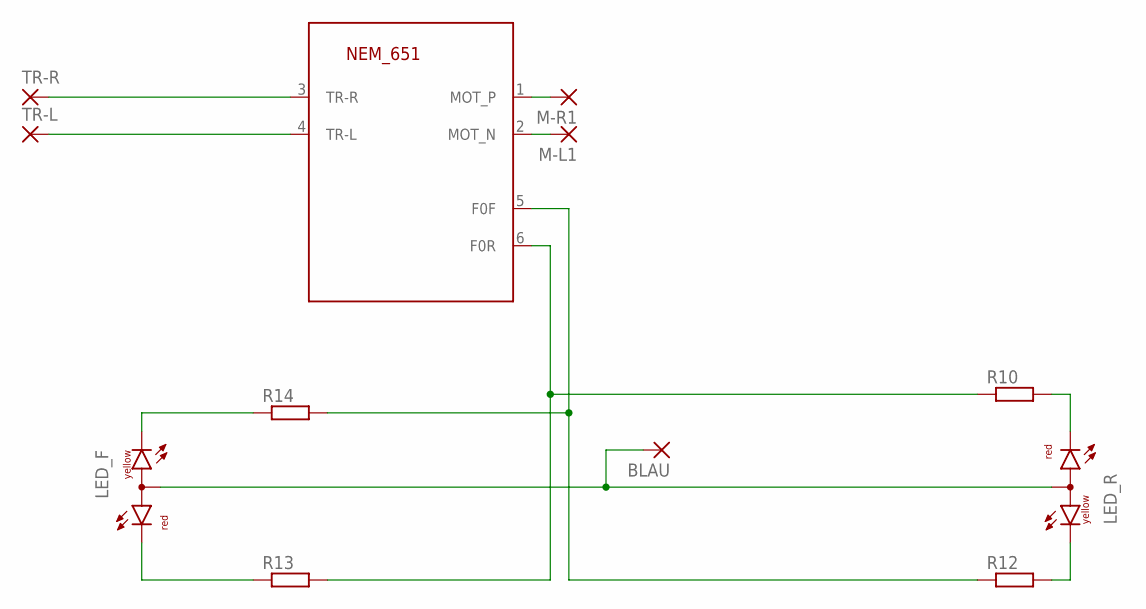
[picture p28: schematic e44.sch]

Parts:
651: NEM_651-TS; 53047-06
BLAU: 1,6/0,8
LED_F: DUOLED-RY-A; DUOLED-A-5MM
LED_R: DUOLED-RY-A; DUOLED-A-5MM
M-L1: SMD5; SMD2,54-5,08
M-R1: SMD5; SMD2,54-5,08
R10, R12, R13, R14: R-EU_R1206; R1206
TR-L: SMD5; SMD2,54-5,08
TR-R: SMD5; SMD2,54-5,08

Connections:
unnamed: BLAU.1, LED_F.A, LED_R.A
unnamed: 651.4 (TR-L), TR-L.1
unnamed: 651.3 (TR-R), TR-R.1
unnamed: 651.5 (F0F), R12.1, R14.2
unnamed: LED_R.CR, R10.2
unnamed: LED_R.CX (CY), R12.2
unnamed: 651.6 (F0R), R10.1, R13.2
unnamed: LED_F.CR, R13.1
unnamed: LED_F.CX (CY), R14.1
unnamed: 651.1 (MOT_P), M-R1.1
unnamed: 651.2 (MOT_N), M-L1.1

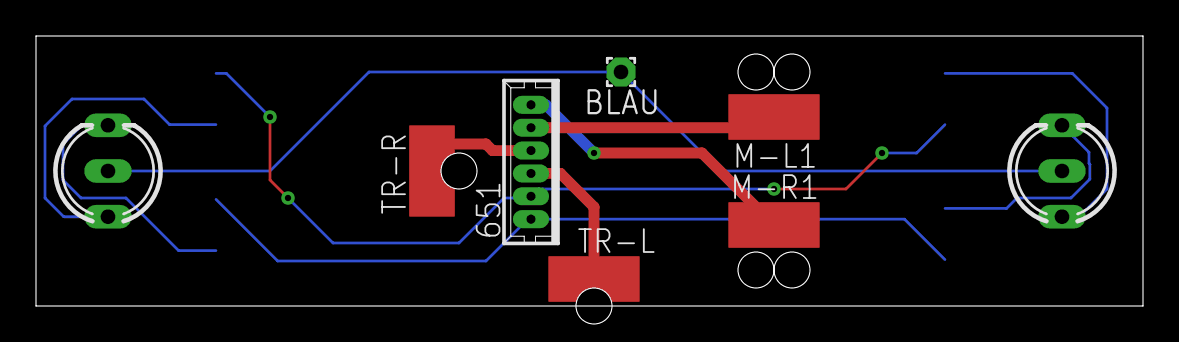
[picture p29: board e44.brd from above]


Board: 2 copper layers, 61.5 x 15.0 mm, 12 parts (4 on the bottom side), 11 nets.

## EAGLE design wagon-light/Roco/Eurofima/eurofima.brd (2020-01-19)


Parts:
B1: MB4S; SOIC-4
C1: 47p; C0805
C2, C3: 100n; C3216
C4, C6, C7, C8, C9, C10: 10u/35V; C3216
C5: 1u/10V; C3216
D1: 1A/40V/500mV; SMA-DIODE
IC2: 78L05F; SOT89
IC3: 16F18324-SL; SO-14
JP3, JP4: PINHD-1X1; 1X01
LED1, LED2, LED3, LED4, LED5, LED6, LED7, LED8, LED9, LED10, LED11, LED12, LED13, LED14, LED15, LED16: LEDKA-3528ASYC; KA-3528ASYC
LED17, LED18: LED3MM
Q1: BC817-25SMD; SOT23-BEC
R1: 220R; R1206
R2: 1k5; R1206
R7: 22k; R1206
R8, R11: 10k; R1206
U1, U2, U3, U4, U5, U6: BCR421U; SC74-6

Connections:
60MA: IC3.3 (T1G/OSC2/CLKOUT/AN3/RA4), R2.2
+5V: C2.1, C5.1, IC2.1 (VO), IC3.1 (VDD), R11.1
+15V: C3.2, C4.1, C6.1, C7.1, C8.1, C9.1, C10.1, D1.C, IC2.3 (VI), LED1.A, LED5.A, LED9.A, LED13.A, LED17.A, LED18.A
COMMAND: C1.2, IC3.11 (COUT/T0CKI/INT/AN2/RA2), R7.2, R8.2
GND: B1.-, C1.1, C2.2, C3.1, C4.2, C5.2, C6.2, C7.2, C8.2, C9.2, C10.2, IC2.2 (GND), IC2.2@1 (GND), IC3.14 (VSS), Q1.E, R8.1, U1.4 (GND), U2.4 (GND), U3.4 (GND), U4.4 (GND), U5.4 (GND), U6.4 (GND)
unnamed: B1.~2 (AC2), JP4.1
unnamed: B1.~1 (AC1), D1.A, JP3.1, R7.1
unnamed: Q1.C, R1.1
unnamed: Q1.B, R2.1
unnamed: B1.+, R1.2
unnamed: LED3.C, LED4.A
unnamed: LED7.C, LED8.A
unnamed: LED11.C, LED12.A
unnamed: LED15.C, LED16.A
unnamed: LED16.C, U4.2 (OUT), U4.3 (OUT), U4.5 (OUT)
unnamed: LED14.C, LED15.A
unnamed: LED10.C, LED11.A
unnamed: LED6.C, LED7.A
unnamed: LED2.C, LED3.A
unnamed: LED1.C, LED2.A
unnamed: LED5.C, LED6.A
unnamed: LED9.C, LED10.A
unnamed: LED13.C, LED14.A
unnamed: LED17.K (C), U5.2 (OUT), U5.3 (OUT), U5.5 (OUT)
unnamed: IC3.4 (VPP/MCLR/RA3), R11.2
unnamed: LED18.K (C), U6.2 (OUT), U6.3 (OUT), U6.5 (OUT)
unnamed: LED4.C, U1.2 (OUT), U1.3 (OUT), U1.5 (OUT)
unnamed: LED12.C, U3.2 (OUT), U3.3 (OUT), U3.5 (OUT)
unnamed: LED8.C, U2.2 (OUT), U2.3 (OUT), U2.5 (OUT)
PWM1: IC3.5 (RC5), U1.1 (EN)
PWM2: IC3.9 (RC1/AN5), U2.1 (EN)
PWM3: IC3.8 (RC2/AN6), U3.1 (EN)
PWM4: IC3.7 (RC3/AN7), U4.1 (EN)
PWM5: IC3.2 (OSC1/CLKIN/T1CKI/RA5), U5.1 (EN)
PWM6: IC3.10 (RC0/AN4), U6.1 (EN)



Board: 2 copper layers, 155.0 x 12.0 mm, 46 parts (18 on the bottom side), 35 nets.

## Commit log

2020-01-19 roco eurofima
    [eurofima.sch]
2020-01-19 legacy loc decoder
    [br215.brd, br215.sch, br44.brd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]
2020-08-12 changed dir structure
    [br215.brd, br215.sch, br44.brd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]
2021-01-11 BR44 nut soldermask correction
    [br44.brd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]

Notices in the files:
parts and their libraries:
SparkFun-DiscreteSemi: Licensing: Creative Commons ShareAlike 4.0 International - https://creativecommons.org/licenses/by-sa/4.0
